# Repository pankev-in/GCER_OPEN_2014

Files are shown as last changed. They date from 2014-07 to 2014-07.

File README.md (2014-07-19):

GCER_OPEN_2014
==============

GCER OPEN GAME 2014

Concept:
	-Mechanical:
		two arms, one to hang the hangers on to the Rack,and another one will just attack opponents' side rack

	-Electronic+Controller:
		2 different voltage regulator:
			8V for motors and controller
			5V for Servos
		using Arduino Mega 2560 as the low level communication processor to controll ther hardware
		Raspberry Pi for extential programming tool or other

Game flow:
	1. Robot adjust at frist in the Starting box with hangers on the Robot.
	2. Drive directly to the Side Rack and hang those two hangers on it.
	3. Return to the black tape and turn left to adjust the position.
	4. Drive ahead to the Center Rack and get the other hangers.
	5. Back to Side Rack and put hangers on it.
	... Repeating...
	?. Drive direct to the Opponents' side 
	?. turn around and distroy them XD(Better with some mario musik~).

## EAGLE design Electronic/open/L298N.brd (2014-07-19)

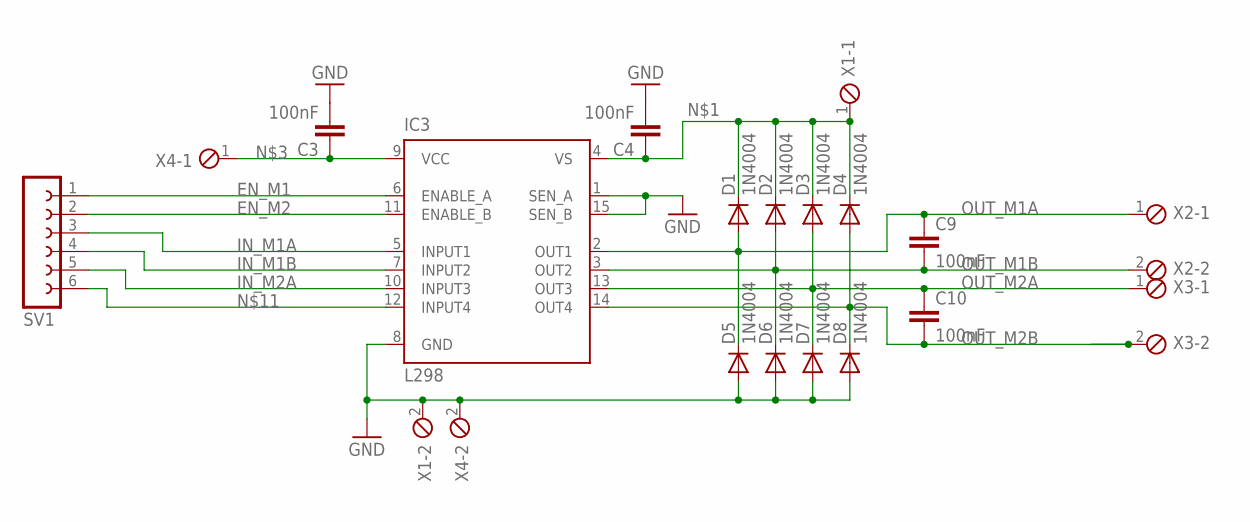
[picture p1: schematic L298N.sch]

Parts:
C3, C4, C9, C10: 100nF; C050-050X075
D1, D2, D3, D4, D5, D6, D7, D8: 1N4004; DO41-10
IC3: L298; MULTIWATT-15
SV1: FE06-1; FE06
X1, X2, X3, X4: MPT2; 2POL254

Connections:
EN_M1: IC3.6 (ENABLE_A), SV1.1
EN_M2: IC3.11 (ENABLE_B), SV1.2
GND: C3.2, C4.2, D5.A, D6.A, D7.A, D8.A, IC3.1 (SEN_A), IC3.8 (GND), IC3.15 (SEN_B), X1.2, X4.2
IN_M1A: IC3.5 (INPUT1), SV1.3
IN_M1B: IC3.7 (INPUT2), SV1.4
IN_M2A: IC3.10 (INPUT3), SV1.5
unnamed: C4.1, D1.C, D2.C, D3.C, D4.C, IC3.4 (VS), X1.1
unnamed: C3.1, IC3.9 (VCC), X4.1
unnamed: IC3.12 (INPUT4), SV1.6
OUT_M1A: C9.1, D1.A, D5.C, IC3.2 (OUT1), X2.1
OUT_M1B: C9.2, D2.A, D6.C, IC3.3 (OUT2), X2.2
OUT_M2A: C10.1, D3.A, D7.C, IC3.13 (OUT3), X3.1
OUT_M2B: C10.2, D4.A, D8.C, IC3.14 (OUT4), X3.2

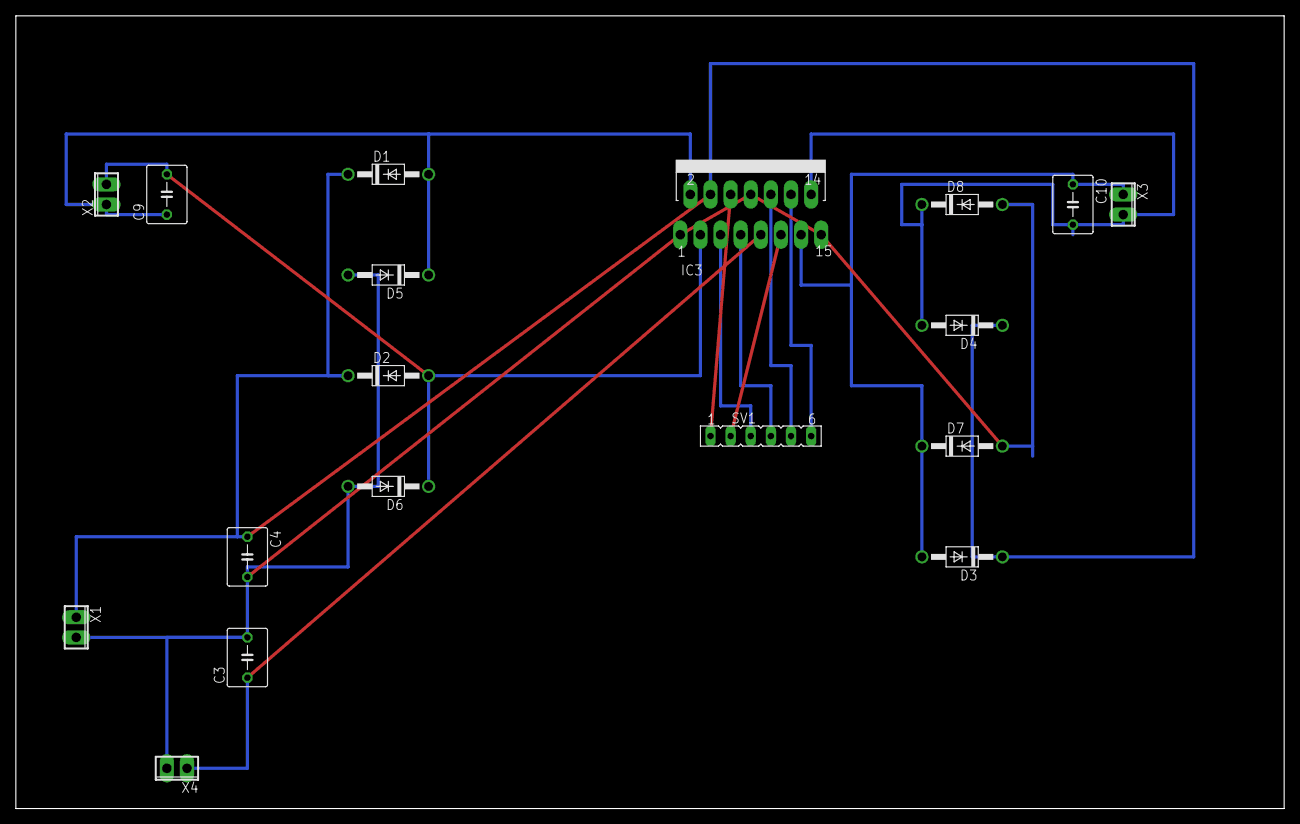
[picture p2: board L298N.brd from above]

Board: 2 copper layers, 160.0 x 100.0 mm, 18 parts (0 on the bottom side), 13 nets.

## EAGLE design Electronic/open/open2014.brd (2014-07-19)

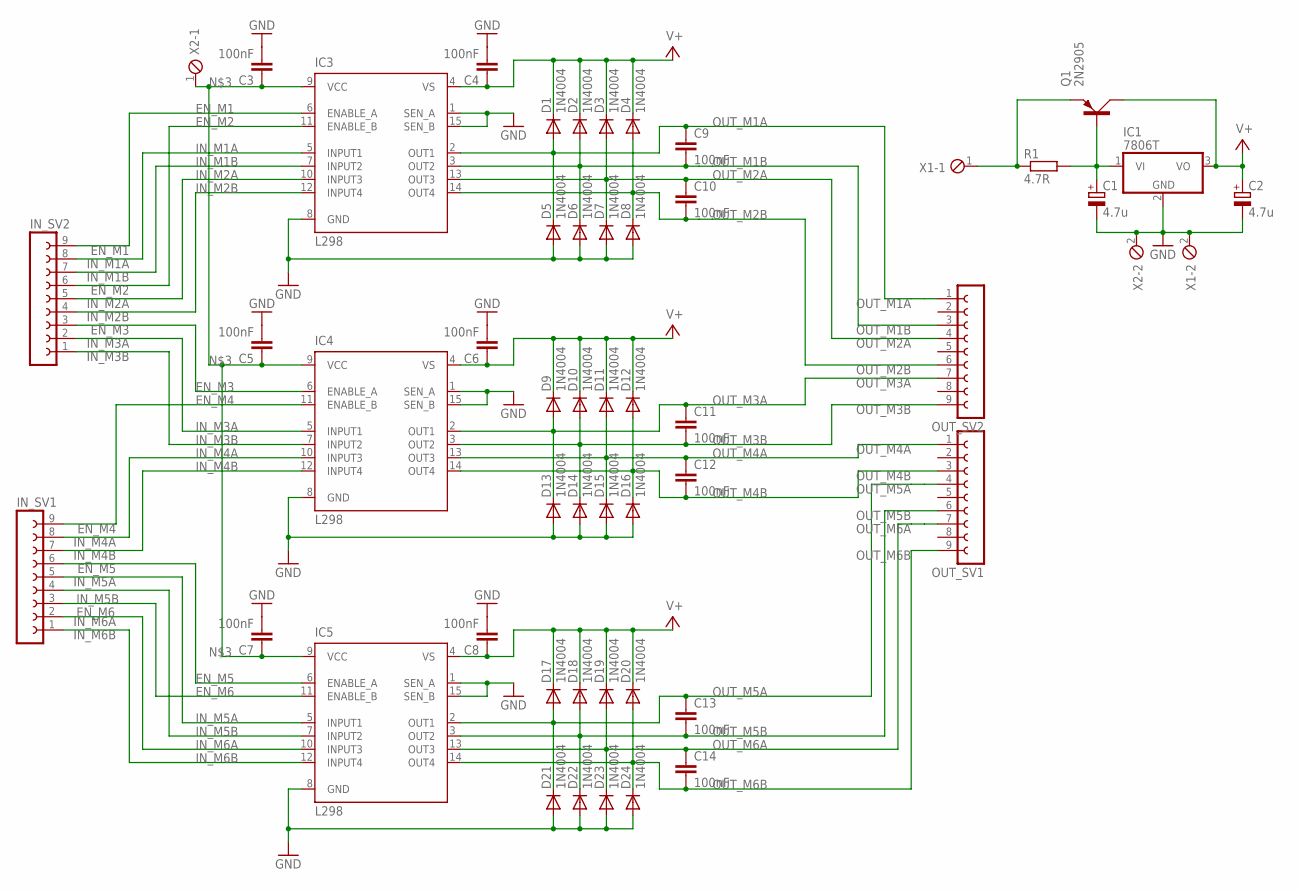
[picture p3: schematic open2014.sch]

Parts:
C1, C2: 4.7u; E2,5-6
C3, C4, C5, C6, C7, C8, C9, C10, C11, C12, C13, C14: 100nF; C050-050X075
D1, D2, D3, D4, D5, D6, D7, D8, D9, D10, D11, D12, D13, D14, D15, D16, D17, D18, D19, D20, D21, D22, D23, D24: 1N4004; DO41-10
IC1: 7806T; TO220H
IC3, IC4, IC5: L298; MULTIWATT-15
IN_SV1, IN_SV2: FE09-1; FE09
OUT_SV1, OUT_SV2: FE09-1; FE09
Q1: 2N2905; TO39
R1: 4.7R; 0411/15
X1, X2: MPT2; 2POL254

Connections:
EN_M1: IC3.6 (ENABLE_A), IN_SV2.9
EN_M2: IC3.11 (ENABLE_B), IN_SV2.6
EN_M3: IC4.6 (ENABLE_A), IN_SV2.3
EN_M4: IC4.11 (ENABLE_B), IN_SV1.9
EN_M5: IC5.6 (ENABLE_A), IN_SV1.6
EN_M6: IC5.11 (ENABLE_B), IN_SV1.3
GND: C1.-, C2.-, C3.2, C4.2, C5.2, C6.2, C7.2, C8.2, D5.A, D6.A, D7.A, D8.A, D13.A, D14.A, D15.A, D16.A, D21.A, D22.A, D23.A, D24.A, IC1.2 (GND), IC3.1 (SEN_A), IC3.8 (GND), IC3.15 (SEN_B), IC4.1 (SEN_A), IC4.8 (GND), IC4.15 (SEN_B), IC5.1 (SEN_A), IC5.8 (GND), IC5.15 (SEN_B), X1.2, X2.2
IN_M1A: IC3.5 (INPUT1), IN_SV2.8
IN_M1B: IC3.7 (INPUT2), IN_SV2.7
IN_M2A: IC3.10 (INPUT3), IN_SV2.5
IN_M2B: IC3.12 (INPUT4), IN_SV2.4
IN_M3A: IC4.5 (INPUT1), IN_SV2.2
IN_M3B: IC4.7 (INPUT2), IN_SV2.1
IN_M4A: IC4.10 (INPUT3), IN_SV1.8
IN_M4B: IC4.12 (INPUT4), IN_SV1.7
IN_M5A: IC5.5 (INPUT1), IN_SV1.5
IN_M5B: IC5.7 (INPUT2), IN_SV1.4
IN_M6A: IC5.10 (INPUT3), IN_SV1.2
IN_M6B: IC5.12 (INPUT4), IN_SV1.1
unnamed: Q1.1 (E), R1.1, X1.1
unnamed: C1.+, IC1.1 (VI), Q1.2 (B), R1.2
unnamed: C3.1, C5.1, C7.1, IC3.9 (VCC), IC4.9 (VCC), IC5.9 (VCC), X2.1
OUT_M1A: C9.1, D1.A, D5.C, IC3.2 (OUT1), OUT_SV2.1
OUT_M1B: C9.2, D2.A, D6.C, IC3.3 (OUT2), OUT_SV2.3
OUT_M2A: C10.1, D3.A, D7.C, IC3.13 (OUT3), OUT_SV2.4
OUT_M2B: C10.2, D4.A, D8.C, IC3.14 (OUT4), OUT_SV2.6
OUT_M3A: C11.1, D9.A, D13.C, IC4.2 (OUT1), OUT_SV2.7
OUT_M3B: C11.2, D10.A, D14.C, IC4.3 (OUT2), OUT_SV2.9
OUT_M4A: C12.1, D11.A, D15.C, IC4.13 (OUT3), OUT_SV1.1
OUT_M4B: C12.2, D12.A, D16.C, IC4.14 (OUT4), OUT_SV1.3
OUT_M5A: C13.1, D17.A, D21.C, IC5.2 (OUT1), OUT_SV1.4
OUT_M5B: C13.2, D18.A, D22.C, IC5.3 (OUT2), OUT_SV1.6
OUT_M6A: C14.1, D19.A, D23.C, IC5.13 (OUT3), OUT_SV1.7
OUT_M6B: C14.2, D20.A, D24.C, IC5.14 (OUT4), OUT_SV1.9
V+: C2.+, C4.1, C6.1, C8.1, D1.C, D2.C, D3.C, D4.C, D9.C, D10.C, D11.C, D12.C, D17.C, D18.C, D19.C, D20.C, IC1.3 (VO), IC3.4 (VS), IC4.4 (VS), IC5.4 (VS), Q1.3 (C)

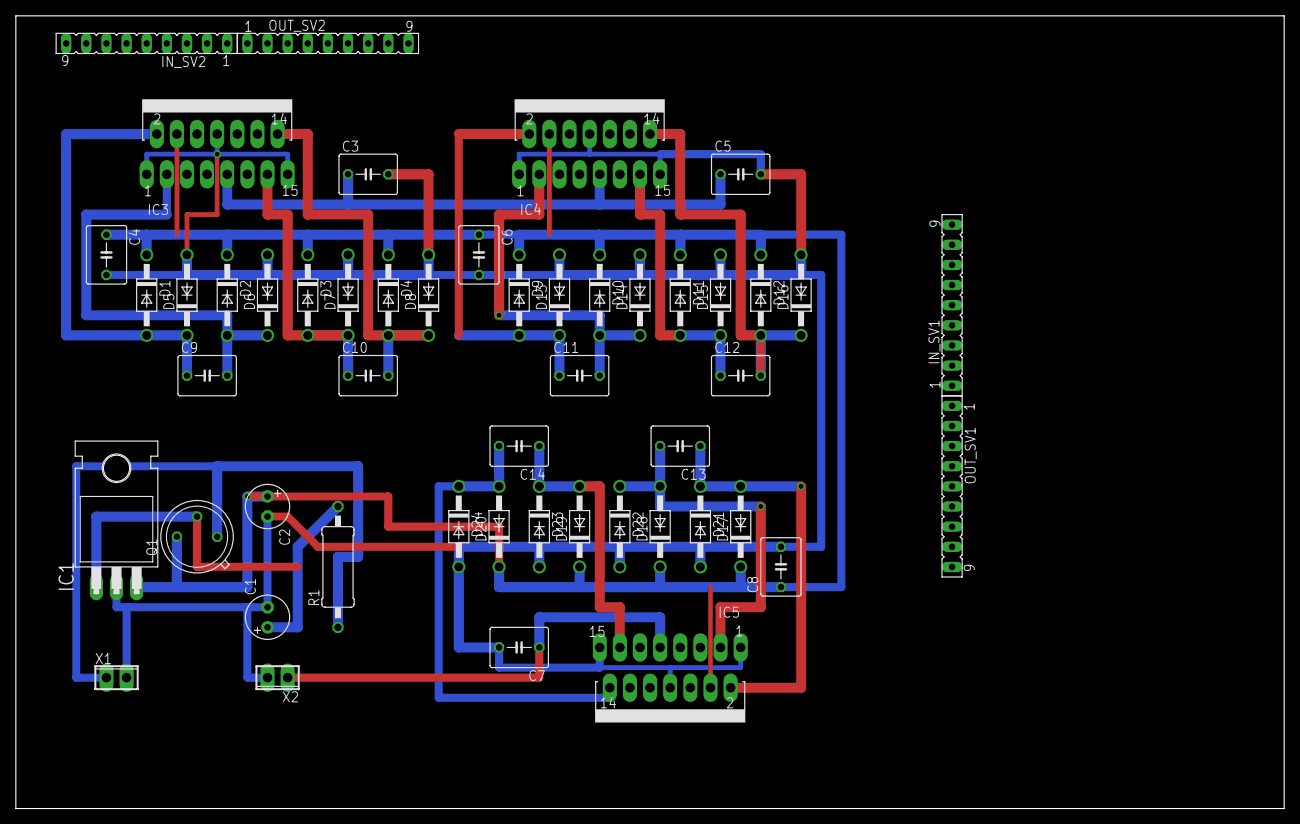
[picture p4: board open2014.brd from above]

Board: 2 copper layers, 160.0 x 100.0 mm, 50 parts (0 on the bottom side), 35 nets.

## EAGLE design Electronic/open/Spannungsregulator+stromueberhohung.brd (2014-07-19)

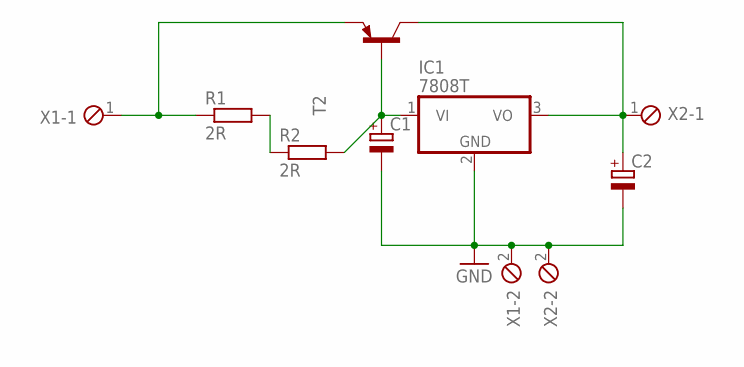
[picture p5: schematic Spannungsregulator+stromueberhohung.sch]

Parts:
C1, C2: CPOL-EUE2,5-6E; E2,5-6E
IC1: 7808T; TO220H
R1, R2: 2R; 0204/7
T2: -PNP-TO220V; TO220V
X1, X2: MPT2; 2POL254

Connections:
GND: C1.-, C2.-, IC1.2 (GND), X1.2, X2.2
unnamed: R1.2, R2.1
unnamed: C1.+, IC1.1 (VI), R2.2, T2.1 (B)
unnamed: R1.1, T2.3 (E), X1.1
unnamed: C2.+, IC1.3 (VO), T2.2 (C), X2.1

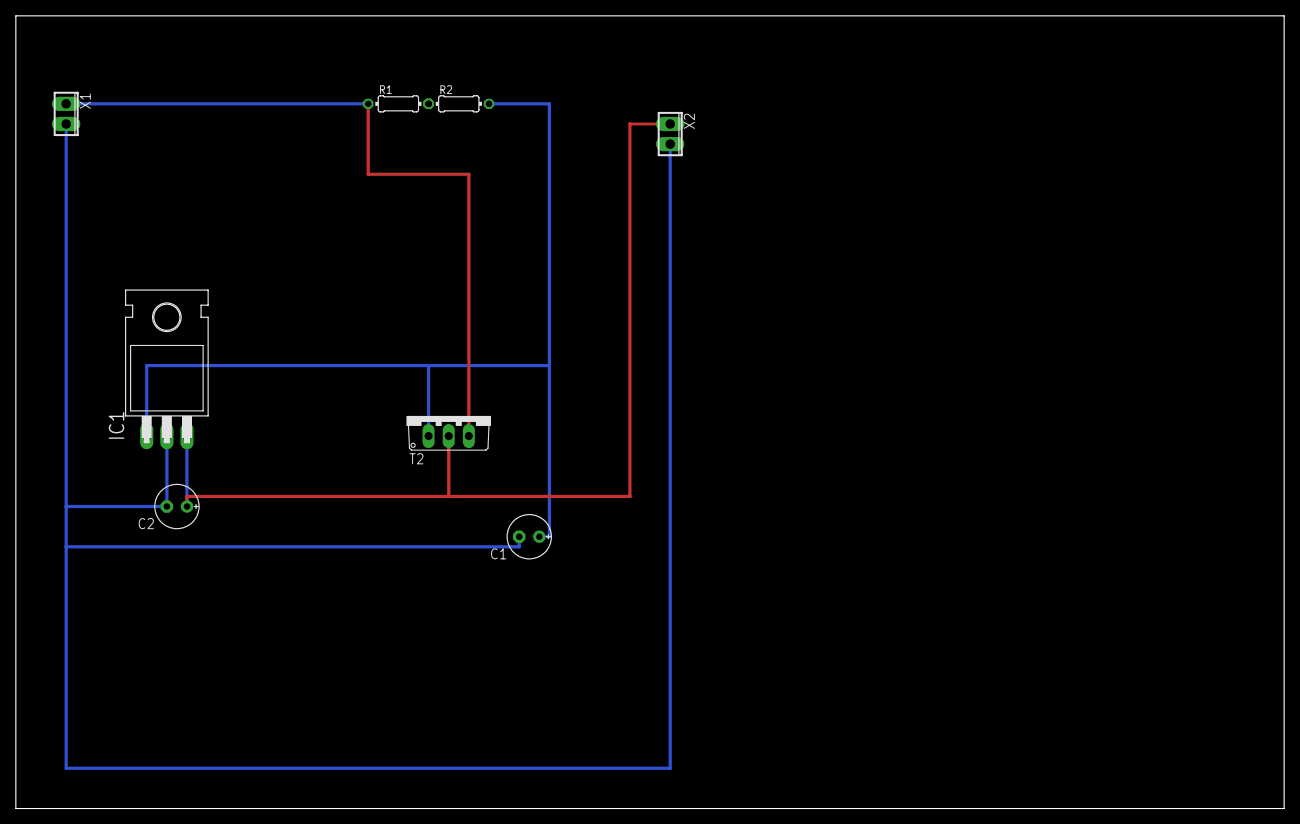
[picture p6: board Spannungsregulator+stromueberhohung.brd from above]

Board: 2 copper layers, 160.0 x 100.0 mm, 8 parts (0 on the bottom side), 5 nets.

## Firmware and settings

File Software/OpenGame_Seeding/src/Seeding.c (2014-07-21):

/*
 	Program: GCER 2014 OPEN GAME - Double Al.
 	Member: Kalus Ableitinger , Kevin Pan
 	Date: 07.2014
*/

//External libraries:
#include <Roomba.h>
#include <Servo.h>
#include <Motor.h>

//Pin connections:
#define M1_EN_PIN 2
#define M1_INA_PIN 22
#define M1_INB_PIN 23
#define M2_EN_PIN 3
#define M2_INA_PIN 24
#define M2_INB_PIN  25
#define SERVO_FRONT_PIN  4
#define SERVO_BACK_PIN  5
#define SERVO_GRAB_PIN  6
#define SERVO_DEFENSE_PIN 7
#define LIGHT_SENSOR_PIN  0
#define POTENTIOMETER_1_PIN  1
#define POTENTIOMETER_2_PIN  2

//Constants:
#define NUM_SERVO_FRONT_ZERO_DEGREE 90
#define NUM_SERVO_BACK_ZERO_DEGREE 95
#define NUM_SERVO_GRAB_CLOSE 0
#define NUM_SERVO_GRAB_OPEN 100
#define NUM_POTENTIOMETER_1_ZERO_DEGREE 330
#define NUM_POTENTIOMETER_1_MAX_ANGLE 108
#define NUM_POTENTIOMETER_1_MIN_ANGLE -98
#define NUM_POTENTIOMETER_2_ZERO_DEGREE 310
#define NUM_POTENTIOMETER_2_MAX_ANGLE 115
#define NUM_POTENTIOMETER_2_MIN_ANGLE -93
#define NUM_ROOMBA_TURN_SPEED 213
#define NUM_LIGHT_SENSOR_VALUE 40
#define NUM_CLIFF_BLACKTAPE_VALUE 200

//Objects define:
Roomba roomba (&Serial1);
Servo SERVO_FRONT;
Servo SERVO_BACK;
Servo SERVO_GRAB;
Servo SERVO_DEFENCE;
Motor m1;
Motor m2;

unsigned int u;

void setup() {
    
    Serial.begin(9600);
    Serial.println("Serial communication established");
    SERVO_FRONT.attach(SERVO_FRONT_PIN);
    SERVO_BACK.attach(SERVO_BACK_PIN);
    SERVO_GRAB.attach(SERVO_GRAB_PIN);
	SERVO_DEFENCE.attach(SERVO_DEFENSE_PIN);
	m1.attach(M1_EN_PIN, M1_INA_PIN, M1_INB_PIN);
	m2.attach(M2_EN_PIN, M2_INA_PIN, M2_INB_PIN);
    roomba.start();
    roomba.safeMode();
}

void loop() {
	secondaryArmPosition(-90);
	grabBasePosition(0);
	primaryArmPosition(10);
	SERVO_DEFENCE.write(180);
	openGrab();

	Serial.println("aligning at gametable..");
	roomba.driveDirect(-150,-150);
	delay(4000);
	roomba.driveDirect(150,150);
	delay(1500);
	turnRight();
    roomba.driveDirect(-150, -150);
 
  
	Serial.println("aligned");    
    delay(1000);
    
    roomba.driveDirect(0, 0);
   	
    Serial.println("waiting for light...");
//    while(analogRead(LIGHT_SENSOR_PIN) > NUM_LIGHT_SENSOR_VALUE) delay(10);
    Serial.println("Go!");
    
    roomba.driveDirect(300, 300);
    uint8_t buf[2];
    while(roomba.getSensors(29, buf, 2)) {
        u = bitShiftCombine(buf[0], buf[1]);
        if(u < 500) {
            break;
        }
    }
 	roomba.driveDirect(0,0);
    turnLeft();
	grabBasePosition(45);
	secondaryArmPosition(-40);
	roomba.driveDirect(200,200);
	delay(4000);
	roomba.driveDirect(0,0);


	SERVO_FRONT.detach();
	SERVO_BACK.detach();
	SERVO_DEFENCE.detach();	
	SERVO_GRAB.detach();

	delay(5000);
	robotComeBack();
	while(true){delay(1000);}

}

/*
########################################
	METHOD: ROOMBA SENSOR
########################################
*/

/*
########################################
	METHOD: ROOMBA DRIVE
########################################
*/

void robotComeBack(){
	roomba.driveDirect(300,300);
	delay(2500);
	turnRight();
	roomba.driveDirect(-150,-150);
	delay(6000);
	roomba.driveDirect(0,0);
	roomba.driveDirect(150,150);
	delay(500);
	roomba.driveDirect(0,0);
	turnLeft();
}

// Roomba Creat turns Right(Clock wise):
// Status: TESTED
void turnRight() {
    
    roomba.drive(NUM_ROOMBA_TURN_SPEED, roomba.DriveInPlaceClockwise);
    delay(1000);
    roomba.driveDirect(0, 0);
}

// Roomba Creat turns left(Inclock wise):
// Status: TESTED
void turnLeft() {
    
    roomba.drive(NUM_ROOMBA_TURN_SPEED, roomba.DriveInPlaceCounterClockwise);
    delay(1000);
    roomba.driveDirect(0, 0);
}

// Roomba Creat turns 180(Clock wise):
// Status: TESTED
void turnAround() {
    
    roomba.drive(NUM_ROOMBA_TURN_SPEED, roomba.DriveInPlaceClockwise);
    delay(2000);
    roomba.driveDirect(0, 0);
}

/*
########################################
	METHOD: OTHER
########################################
*/

// Shifting two unsigned int* together, Need for sensor data read:
// Status: TESTED
int bitShiftCombine( unsigned char x_high, unsigned char x_low) {
    
    int combined;
    combined = x_high;             	 //send x_high to rightmost 8 bits
    combined = combined << 8;     	 //shift x_high over to leftmost 8 bits
    combined |= x_low;               //logical OR keeps x_high intact in combined and fills in rightmost 8 bits
    return combined;
}

/*
########################################
	METHOD: THE ROBOT ARM
########################################
*/

void moveAll(int primaryArmPos, int secondaryArmPos, int grabBasePos, int grabPos, int defensePos) {

    if(primaryArmPos > 45|| primaryArmPos < -45) return;
    if(secondaryArmPos > NUM_POTENTIOMETER_1_MAX_ANGLE || secondaryArmPos < NUM_POTENTIOMETER_1_MIN_ANGLE) return;
    if(grabBasePos > NUM_POTENTIOMETER_2_MAX_ANGLE || grabBasePos < NUM_POTENTIOMETER_2_MIN_ANGLE) return;
    if(grabPos > 100 || grabPos < 0) return;
    if(defensePos > 180 || defensePos < 0) return;

    SERVO_FRONT.write(NUM_SERVO_FRONT_ZERO_DEGREE - primaryArmPos);
    SERVO_BACK.write(NUM_SERVO_BACK_ZERO_DEGREE + primaryArmPos);
    
    SERVO_DEFENCE.write(defensePos);
    
    SERVO_GRAB.write(grabPos);
  
    int secondaryDiff = secondaryArmPos - checkSecondaryArmAngle();
	if(secondaryDiff < 5 && secondaryDiff > -5){
        
		Serial.println("Secondary Arm is not going to turn.");
		Serial.print("Diff:");Serial.println(secondaryDiff);
	} else if(secondaryDiff > 0){
        
		m1.forward(255);
	} else if(secondaryDiff < 0){
		m1.backward(255);
	}
    
    int grabDiff = grabBasePosition - checkGrabAngle();
	if(grabDiff < 5 && grabDiff > -5){
        
		Serial.println("Grab is not going to turn.");
		Serial.print("Diff:");Serial.println(grabDiff);
	} else if(grabDiff < 0){
		
        m2.backward(200);
	} else if(grabDiff > 0){
        
		m2.forward(200);
	}
    
	while((grabDiff > 5 || grabDiff < -5) || (secondaryDiff > 5 || secondaryDiff < -5)){
        
        grabDiff = grabBasePos - checkGrabAngle();
        secondaryDiff = secondaryArmPos - checkSecondaryArmAngle();
        
        if(secondaryDiff < 5 || secondaryDiff > -5) m1.break();
        if(grabDiff < 5 || grabDiff > -5) m2.break();
	}
}

// Turn Primary arm in to an specific angle between -45 to 45 degree:
// Status: TESTED
void primaryArmPosition(int Angle) {
    
  if(Angle > 45||Angle < -45) return;
  else{
      
	SERVO_FRONT.write(NUM_SERVO_FRONT_ZERO_DEGREE - Angle);
 	SERVO_BACK.write(NUM_SERVO_BACK_ZERO_DEGREE + Angle);
  }
}

// Turn Secondary arm in to an specific angle between -110 to 110 degree:
// Status: Untested
void secondaryArmPosition(int angle){
	
	if(angle > NUM_POTENTIOMETER_1_MAX_ANGLE || angle < NUM_POTENTIOMETER_1_MIN_ANGLE){		//Check if the input angle is posible
		return;
	}
	int diff =angle - checkSecondaryArmAngle();		//calculate the difference
	if(diff<5&&diff>-5){
		Serial.println("Secondary Arm is not going to turn.");
		Serial.print("Diff:");Serial.println(diff);
	}
	else if(diff>0){
		m1.forward(255);
	}
	else if(diff<0){
		m1.backward(255);
	}
	while(diff>5||diff<-5){
        diff =angle - checkSecondaryArmAngle();
	}
    m1.brake();
}

// Turn the Grabber in to an specific angle between -110 to 110 degree:
// Status: Untested
void grabBasePosition(int angle) {
	
	if(angle > NUM_POTENTIOMETER_2_MAX_ANGLE || angle < NUM_POTENTIOMETER_2_MIN_ANGLE){		//Check if the input angle is posible
		return;
	}
	int diff =angle - checkGrabAngle();		//calculate the difference
	if(diff<5&&diff>-5){
		Serial.println("Grab is not going to turn.");
		Serial.print("Diff:");Serial.println(diff);
	}
	else if(diff<0){
		m2.backward(200);       //Here is Backward!!!!
	}
	else if(diff>0){
		m2.forward(200);
	}
	while(diff>5||diff<-5){
        diff =angle - checkGrabAngle();
	}
    m2.brake();
}

// Returns the Angle of the grabbler:
// Status: TESTED
int checkGrabAngle() {
    
   	int value=analogRead(POTENTIOMETER_2_PIN);
	value=map(value,0,697,NUM_POTENTIOMETER_2_MIN_ANGLE,NUM_POTENTIOMETER_2_MAX_ANGLE);
  	return value;
}

// Returns the Angle of the secondary Arm:
// Status: TESTED
int checkSecondaryArmAngle(){
   	int value=analogRead(POTENTIOMETER_1_PIN);
   	value=map(value,0,697,NUM_POTENTIOMETER_1_MIN_ANGLE,NUM_POTENTIOMETER_1_MAX_ANGLE);
   	return value;}

// Open the grabbler:
// Status: TESTED
void openGrab(){
    
  SERVO_GRAB.write(NUM_SERVO_GRAB_OPEN);
}

// Open the grabbler:
// Status: TESTED
void closeGrab(){
    
  SERVO_GRAB.write(NUM_SERVO_GRAB_CLOSE);
}

bool checkGrabTouch() {
    
    return false;
}

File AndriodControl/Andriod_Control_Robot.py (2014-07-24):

#!/usr/bin/python

import serial
import socket
import sys
from time import sleep
from sys import argv

HOST=''
PORT=0

S1=0;#Slider - Prime Arm Position;
S2=0;#Slider - Secondary Arm Position;
S3=0;#Slider - Defence Arm Position;
S4=0;#Slider - Grab Base Position;
S5=0;#Slider - Grab Position;
B1=0;#Button - 'Forward'
B2=0;#Button - 'Backward'
B3=0;#Button - 'TurnLeft'
B4=0;#Button - 'TurnRight'
SAVE_B=0;
savePressed=False

NUM_POTENTIOMETER_1_MAX_ANGLE=108
NUM_POTENTIOMETER_1_MIN_ANGLE=-98
NUM_POTENTIOMETER_2_MAX_ANGLE=115
NUM_POTENTIOMETER_2_MIN_ANGLE=-93
NUM_SERVO_GRAB_CLOSE=0
NUM_SERVO_GRAB_OPEN=100
NUM_PRIME_MAX_ANGLE=45
NUM_PRIME_MIN_ANGLE=-45
NUM_DEFENCE_MAX_ANGLE=180
NUM_DEFENCE_MIN_ANGLE=0

breakout=0;
BufferSize=128
SliderMax=16384
OutputString=''
InputString=''



#Programstart
print "\n	Programm Started"


#Checking system input values
if len(sys.argv)<2:
	print "\n####################################"
	print "ERROR: Need more input information!!! \n"+"Format:   python XYZ.py [HOST] [Port] "
	print "####################################"
	sys.exit("\n	Programm Ended.\n")

HOST=sys.argv[1]
PORT=int(sys.argv[2])


#Serial connection to Arduino
arduino = serial.Serial("/dev/ttyACM0",9600)
print ("\nSerial Connection with Arduino Created")


#Socket Connection
sock = socket.socket(socket.AF_INET,socket.SOCK_STREAM)
sock.connect((HOST,PORT))
print '\nSocket Connected:'
print "Connected to Host Address:",HOST
print "Connected to Port Number:",PORT,"\n\n"
target = open("robotPosition.txt", 'w');
target.write("\n\n\n")



while True:
	#Buffering Data income:
	InputString=sock.recv(BufferSize)

	#End program by sending '<stop>' string:
	if InputString[1:5] == 'STOP':
		print("Disconnected form Client")
		sys.exit()


	#Editing Values:
	Values=InputString.split(";")
	try:
		B1=int(Values[1]);
		B2=int(Values[2]);
		B3=int(Values[3]);
		B4=int(Values[4]);
		S1=int(Values[5].lstrip("{S").rstrip("}"))
		S2=int(Values[6].lstrip("{S").rstrip("}"))
		S3=int(Values[7].lstrip("{S").rstrip("}"))
		S4=int(Values[8].lstrip("{S").rstrip("}"))
		S5=int(Values[9].lstrip("{S").rstrip("}"))
		B5=Values[10]
		SAVE_B=int(B5[0:1])
		breakout=0;

	except (ValueError,IndexError) as e:
		B1=0;B2=0;B3=0;B4=0;
		breakout=breakout+1
		if breakout>=5:
			sys.exit("\nConnection breaks\n");
		pass


	S1=-int(S1/float(SliderMax)*45)

	if S2>0:
		S2=int(S2/float(SliderMax)*NUM_POTENTIOMETER_1_MIN_ANGLE)
	elif S2<0:
		S2=-int(S2/float(SliderMax)*NUM_POTENTIOMETER_1_MAX_ANGLE)
	
	if S4>0:
		S4=int(S4/float(SliderMax)*NUM_POTENTIOMETER_2_MIN_ANGLE)
	elif S4<0:
		S4=-int(S4/float(SliderMax)*NUM_POTENTIOMETER_2_MAX_ANGLE)
	
	S3=-int((S3-SliderMax)/float(SliderMax)*NUM_DEFENCE_MAX_ANGLE)/2
	S5=-int((S5-SliderMax)/float(SliderMax)*NUM_SERVO_GRAB_OPEN)/2



	#Printing Values on to the screen:
	print "Forward:",B1,"Backward:",B2,"Left:",B3,"Right:",B4
	print "S1: ",S1," S2: ",S2," S3: ",S3," S4: ",S4," S5: ",S5
	OutputString=str(S1)+";"+str(S2)+";"+str(S3)+";"+str(S4)+";"+str(S5)

	if SAVE_B==1:
		print "Save Pressed";
		savePressed=True;
	else:
		if savePressed==True:
			target.write(OutputString)
			target.write("\n")
			savePressed=False;
		print "Save not Pressed"
	
    OutputString=str(B1)+";"+str(B2)+";"+str(B3)+";"+str(B4)+";"+str(S1)+";"+str(S2)+";"+str(S3)+";"+str(S4)+";"+str(S5)+"|"
	arduino.write(OutputString);

	#Reset Variables:
	B1=0;#Button - 'Forward'
	B2=0;#Button - 'Backward'
	B3=0;#Button - 'TurnLeft'
	B4=0;#Button - 'TurnRight'
	InputString=''
	OutputString=''
	Values=''

arduino.close()
target.close()
sock.close()
del sock
print('Programm ended.\n\n')

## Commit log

2014-07-07 first Test Programs
    1.Running create with arduino uno
    2.testing H-Bridge controller
    [Create-Arduino.sch, project.cfg]
2014-07-11 implement Servo.cpp and improve Robot
2014-07-14 sensor test
2014-07-15 Main arm working
2014-07-15 add + tested Motor class
2014-07-17 add motorpsoitioning method
2014-07-18 new board
2014-07-18 Test functions
    Only AnglePostion does’t work
2014-07-19 Finail Change before get start!!!!(this time real)
    Add electrical Circuit
    Add Readme, Game flow
    [L298N.brd, L298N.sch, Spannungsregulator+stromueberhohung.brd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]
